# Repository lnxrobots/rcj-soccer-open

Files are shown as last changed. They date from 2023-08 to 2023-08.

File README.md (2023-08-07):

# RoboCup Soccer Open

## Setup

### Install packages and libraries

```
sudo apt install python3-pip git i2c-tools python3-opencv python3-serial python3-websockets
```

```
sudo pip3 install Adafruit-Blinka adafruit-circuitpython-bno055 adafruit-extended-bus adafruit-circuitpython-ssd1306 pillow bluedot
```

### Enable software I2C and second UART, disable builtin Bluetooth

Add following lines to `/boot/config.txt`:

```
# Software i2c - custom
dtoverlay=i2c-gpio,bus=3

# Second and fifth UART - custom
dtoverlay=uart2
dtoverlay=uart5

# Uncomment to disable builtin bluetooth - custom
#dtoverlay=disable-bt
```

### Pairing robots

Pair using [bluedot manual](https://bluedot.readthedocs.io/en/latest/pairpipi.html).

### Camera

Obtain frames using [Picamera2](https://github.com/raspberrypi/picamera2).

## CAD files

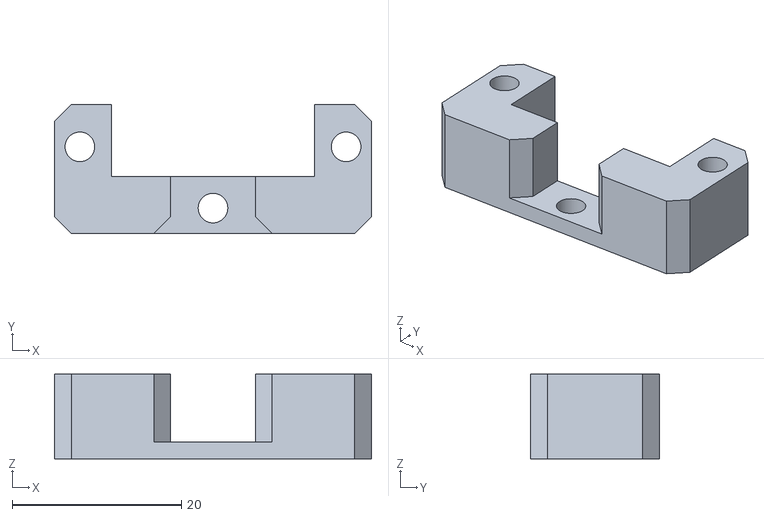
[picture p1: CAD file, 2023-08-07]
Hardware/3D/battery-holders/battery-holder-large-right.stl
37.5 x 15.2 x 10.0

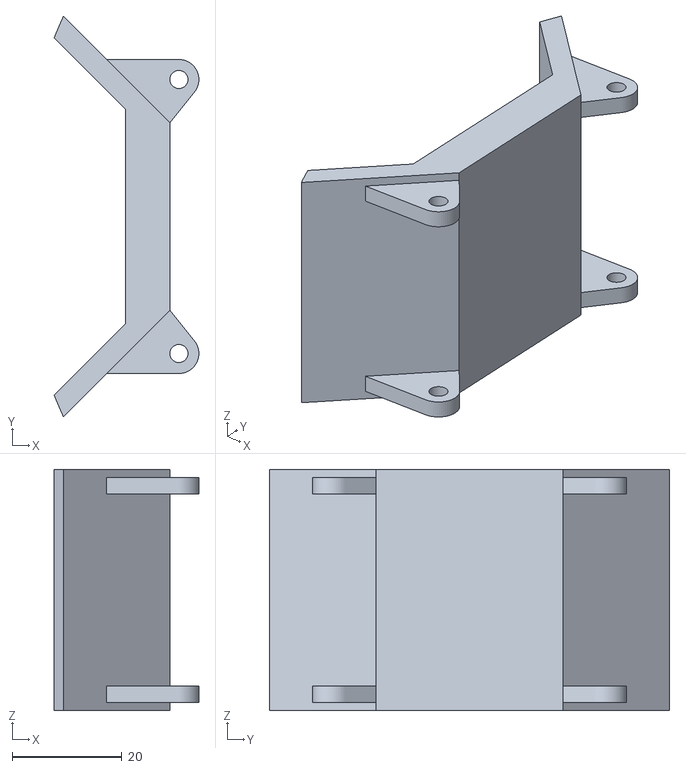
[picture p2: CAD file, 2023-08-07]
Hardware/3D/bumpers-35mm/bumper-front.stl
26.4 x 73.1 x 44.0

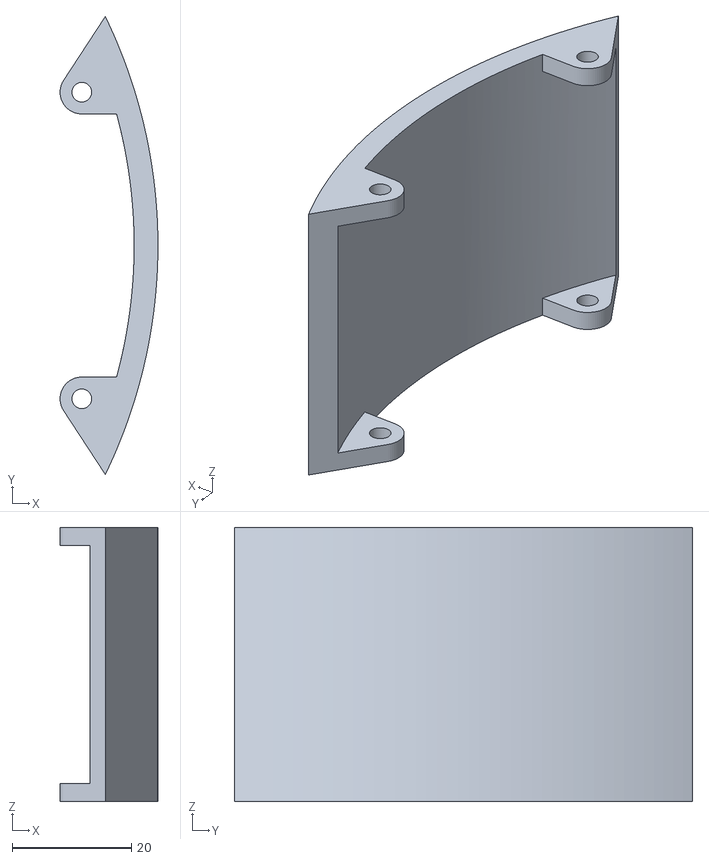
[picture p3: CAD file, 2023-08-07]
Hardware/3D/bumpers-40mm/bumper-40mm-side.stl
16.4 x 76.9 x 46.0

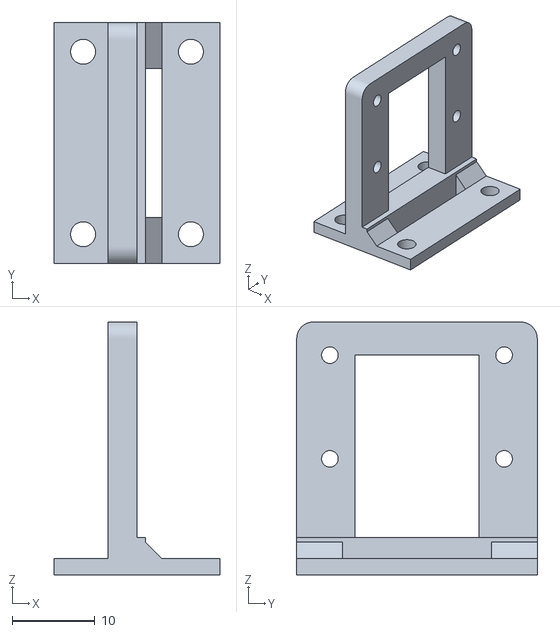
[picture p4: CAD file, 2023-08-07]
Hardware/3D/camera-pcb/camera-mount.stl
20.0 x 29.0 x 30.5

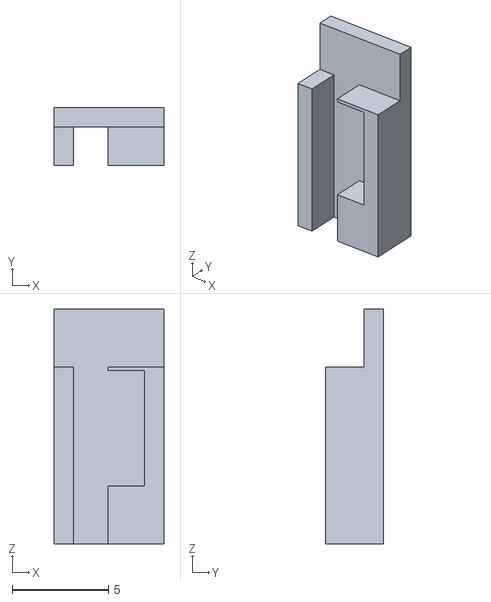
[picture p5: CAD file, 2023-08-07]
Hardware/3D/covers/rpi-led-cover.stl
5.70 x 3.00 x 12.2

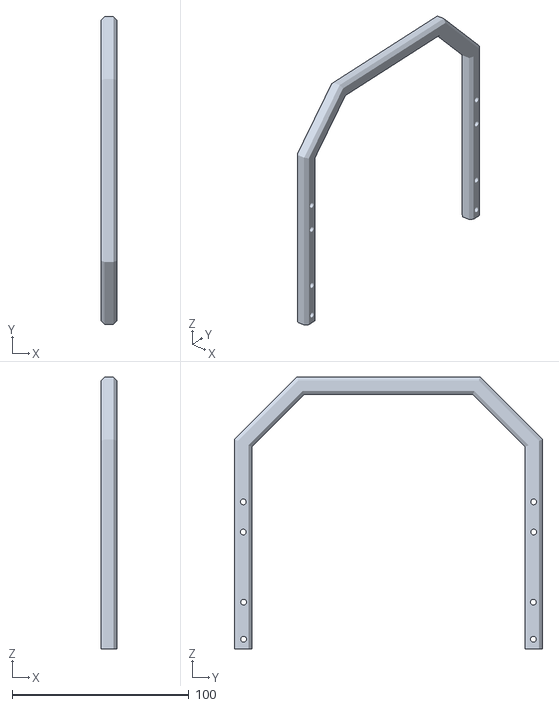
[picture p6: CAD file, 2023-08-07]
Hardware/3D/handle/handle.stl
9.00 x 174.4 x 154.0

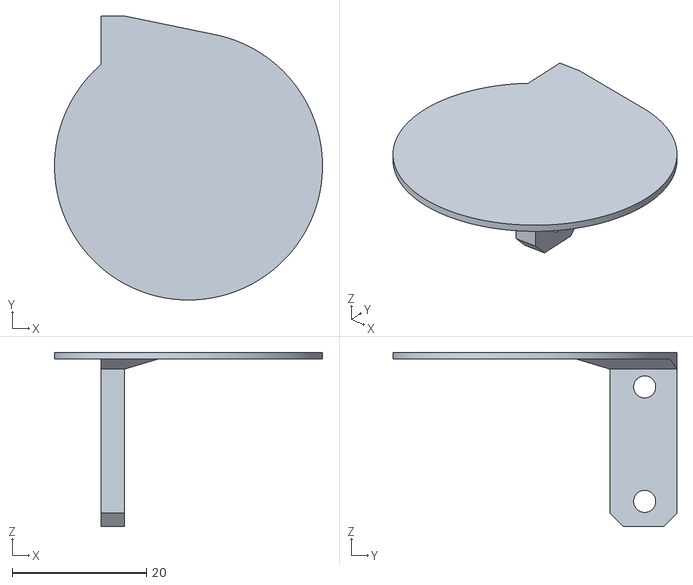
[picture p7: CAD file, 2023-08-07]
Hardware/3D/top-marker.stl
40.0 x 42.4 x 26.0

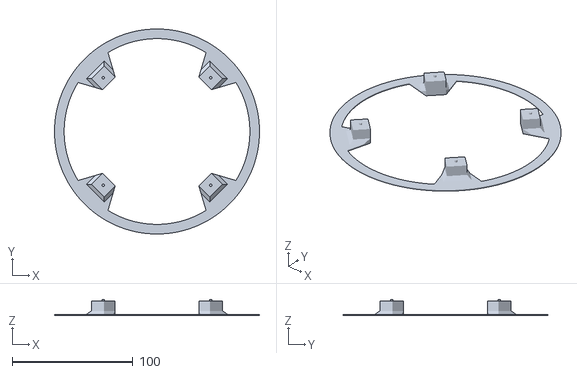
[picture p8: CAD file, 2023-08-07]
Hardware/3D/transport-container-adapter/pad.stl
170.0 x 170.0 x 13.5

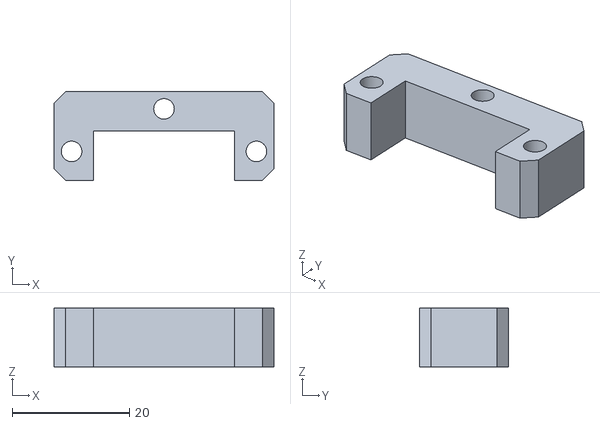
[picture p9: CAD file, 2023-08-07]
Hardware/3D/battery-holders/battery-holder-large-left.stl
37.5 x 15.2 x 10.0

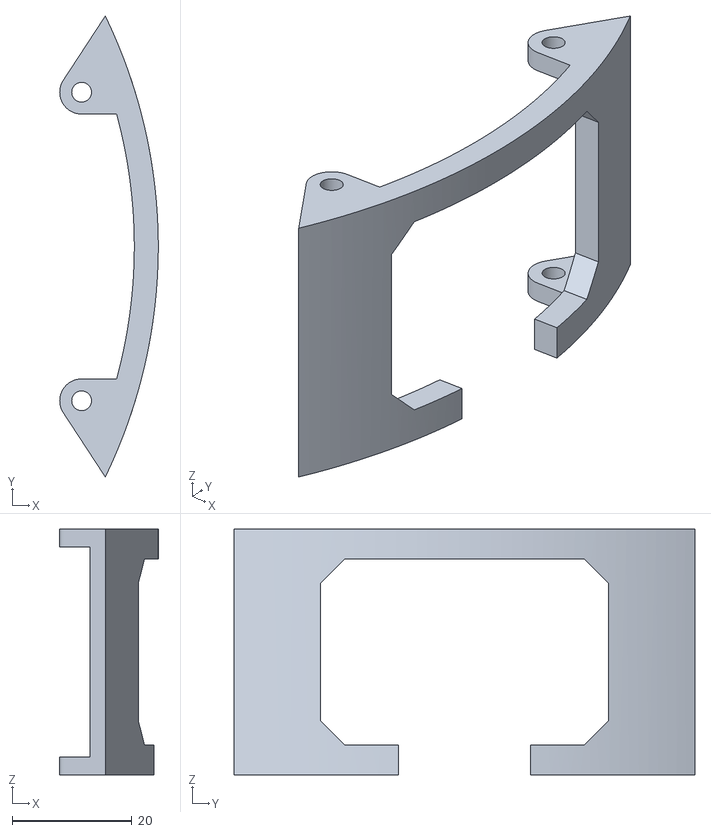
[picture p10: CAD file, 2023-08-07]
Hardware/3D/bumpers-35mm/bumper-rear.stl
16.4 x 76.9 x 41.0

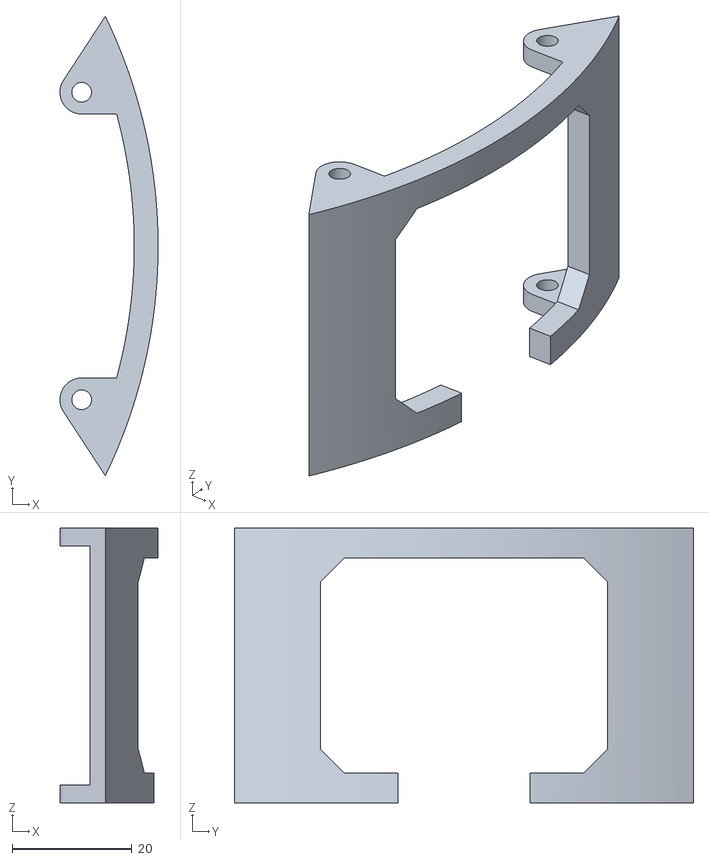
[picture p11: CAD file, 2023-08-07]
Hardware/3D/bumpers-40mm/bumper-40mm-rear.stl
16.4 x 76.9 x 46.0

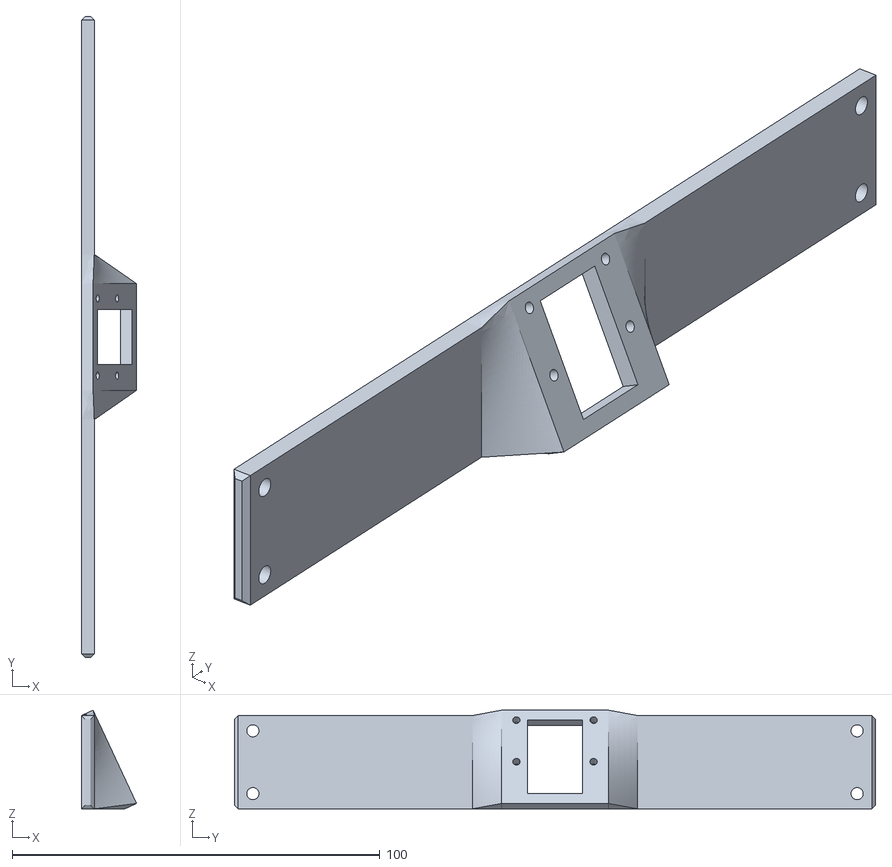
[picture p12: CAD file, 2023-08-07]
Hardware/3D/camera-handle/handle-camera-mount.stl
15.0 x 174.4 x 26.9

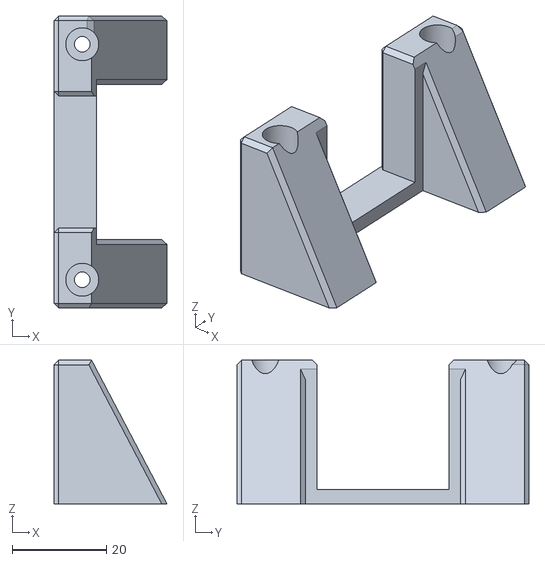
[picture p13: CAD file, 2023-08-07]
Hardware/3D/camera-pcb/camera-protector.stl
24.0 x 62.0 x 30.5

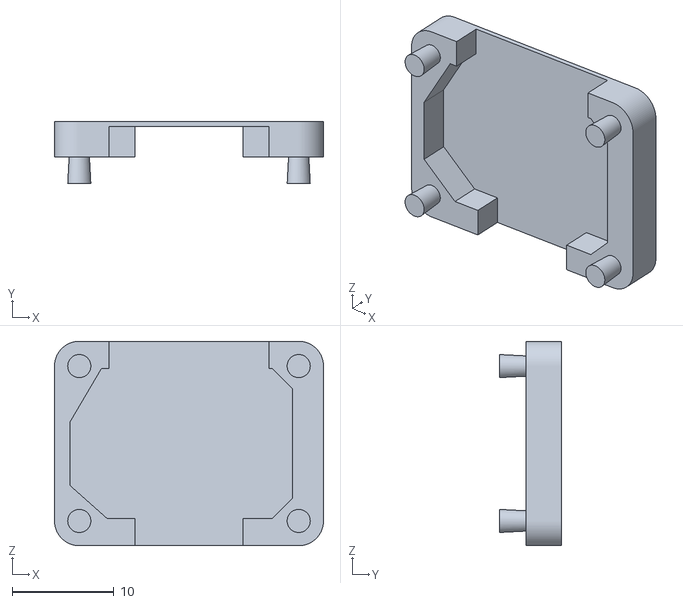
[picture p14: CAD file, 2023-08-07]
Hardware/3D/covers/bno-cover.stl
26.5 x 6.15 x 20.1

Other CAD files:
Hardware/3D/handle/handle-mount.stl
Hardware/3D/rack.stl
Hardware/3D/transport-container-adapter/adapter.stl
Hardware/3D/battery-holders/battery-holder-small-left.stl
Hardware/3D/battery-holders/battery-holder-small-right.stl
Hardware/3D/bumpers-35mm/bumper-side.stl
Hardware/3D/bumpers-40mm/bumper-40mm-front.stl
Hardware/3D/camera-handle/camera-washer.stl
Hardware/3D/motor-screw-washer.stl
Hardware/3D/omniwheel.3mf
Hardware/3D/pcb-shaft.stl
Hardware/3D/rack-only-rpi.stl

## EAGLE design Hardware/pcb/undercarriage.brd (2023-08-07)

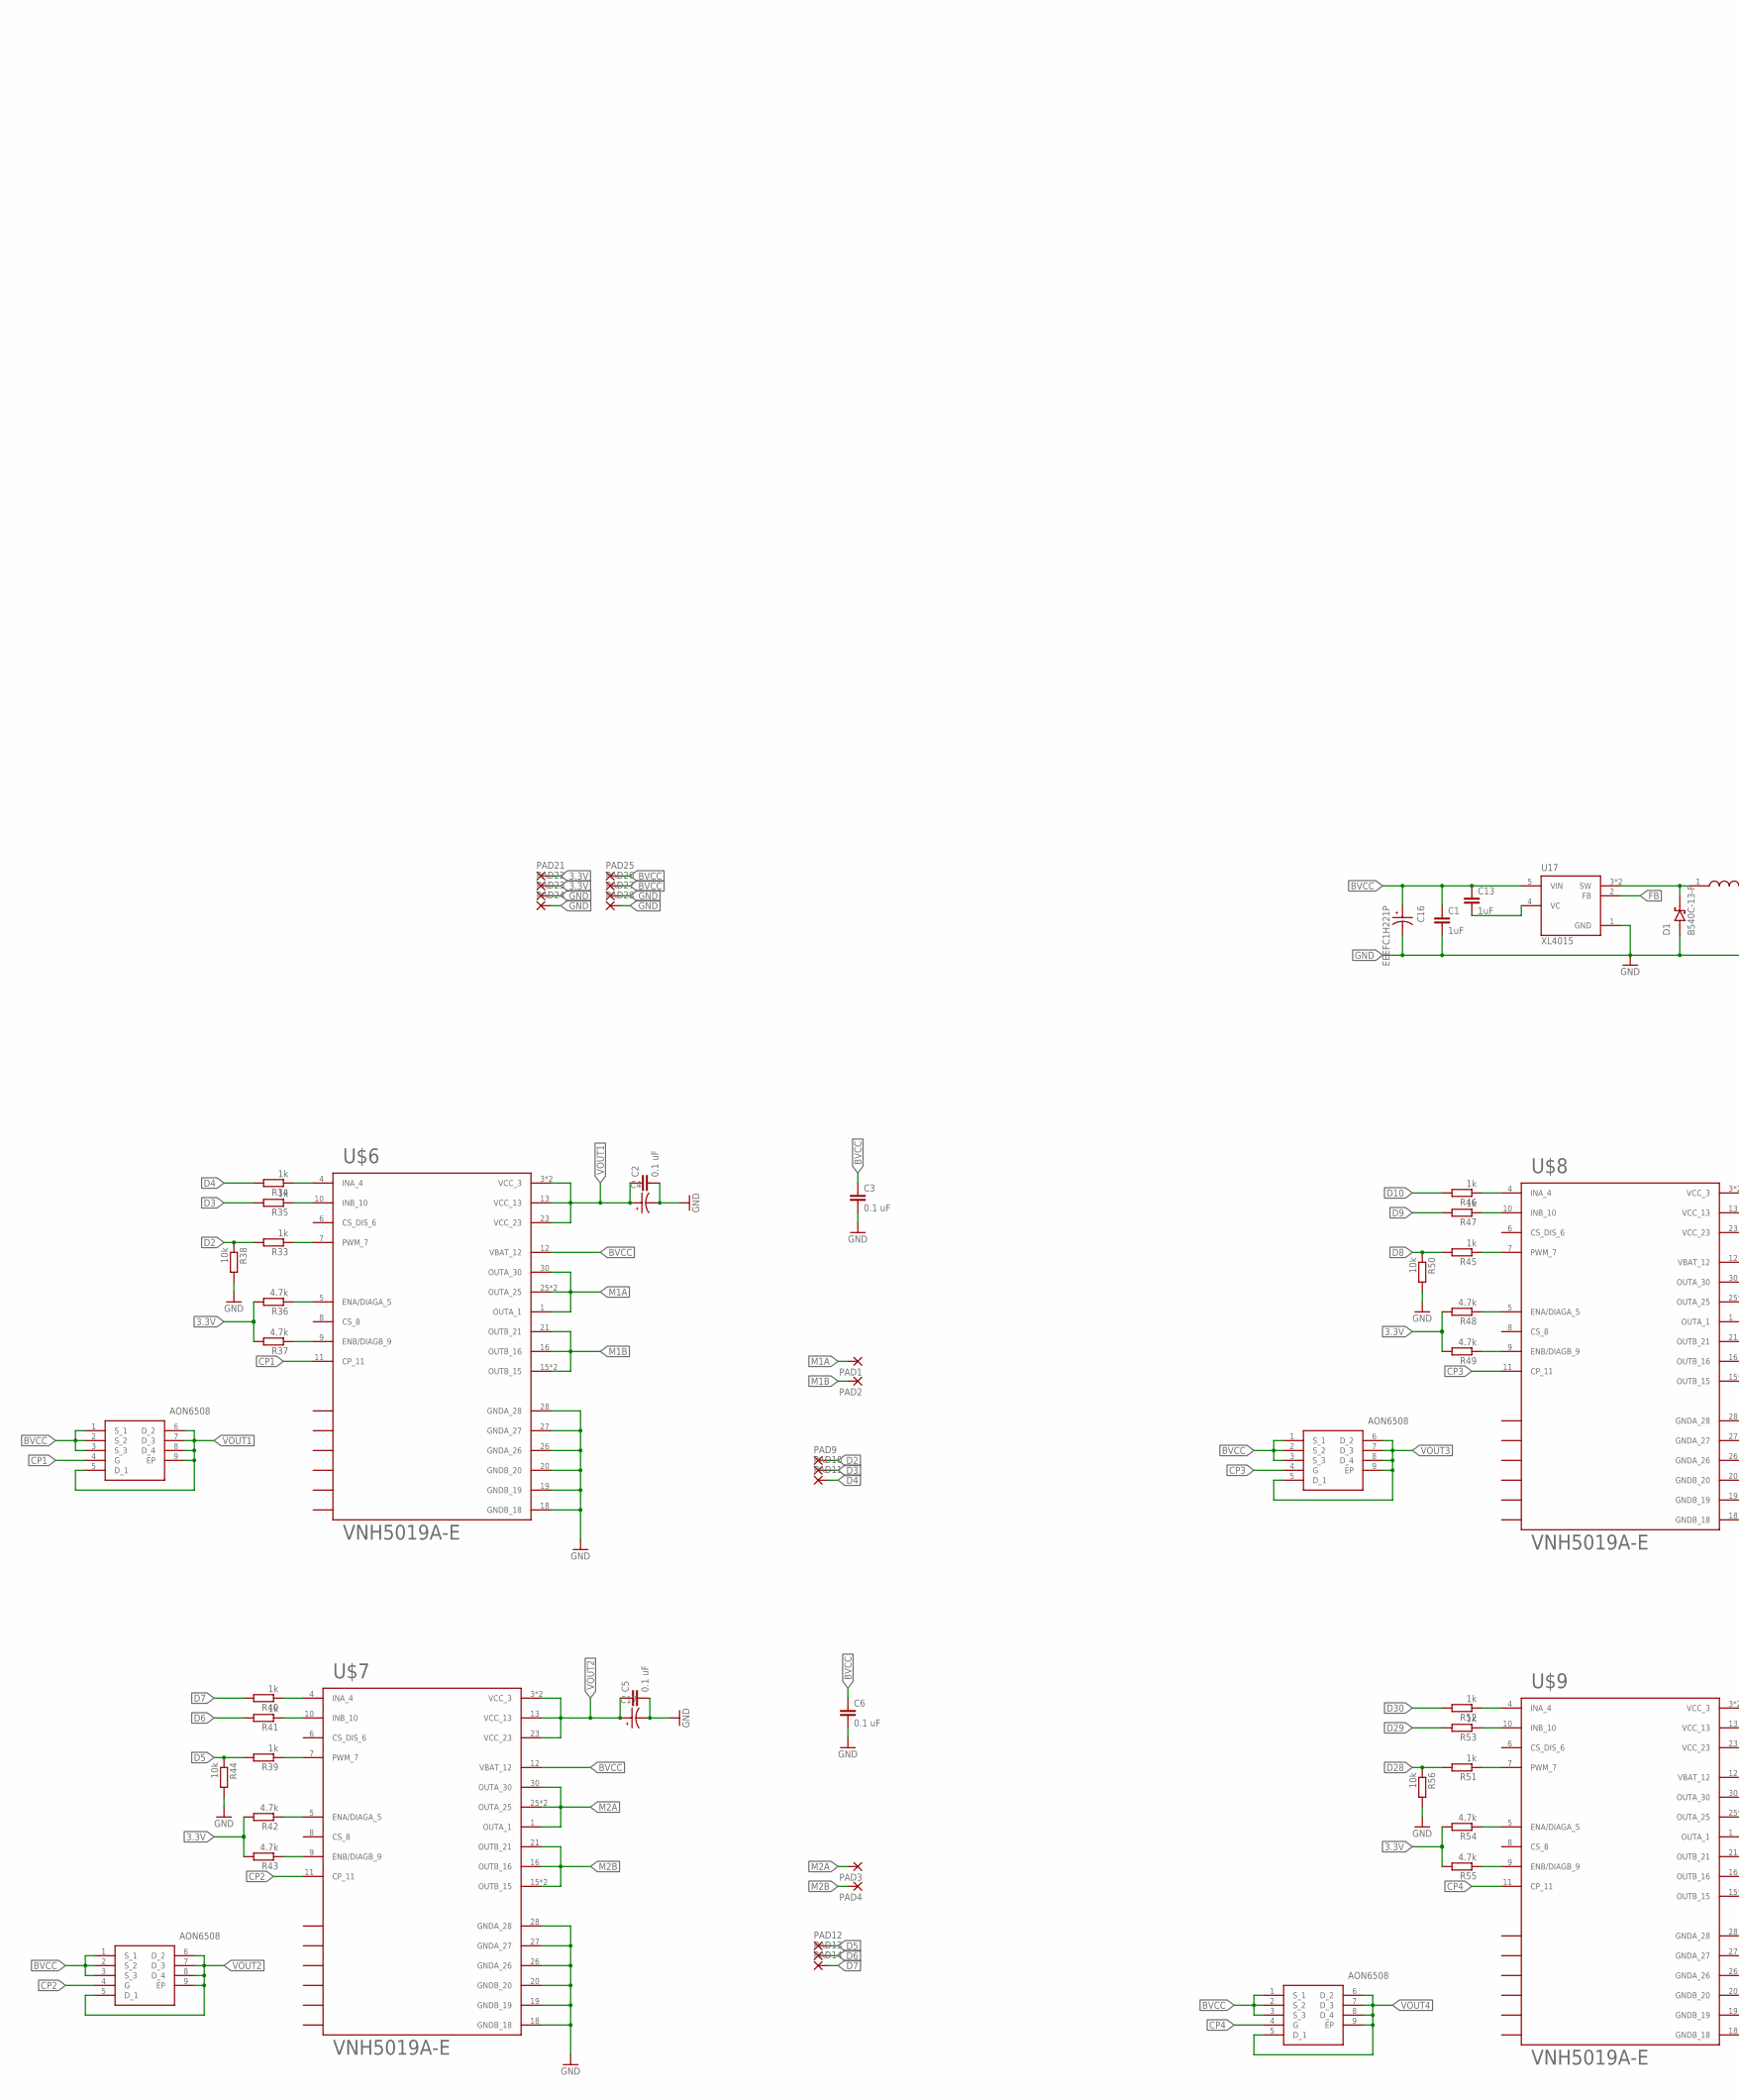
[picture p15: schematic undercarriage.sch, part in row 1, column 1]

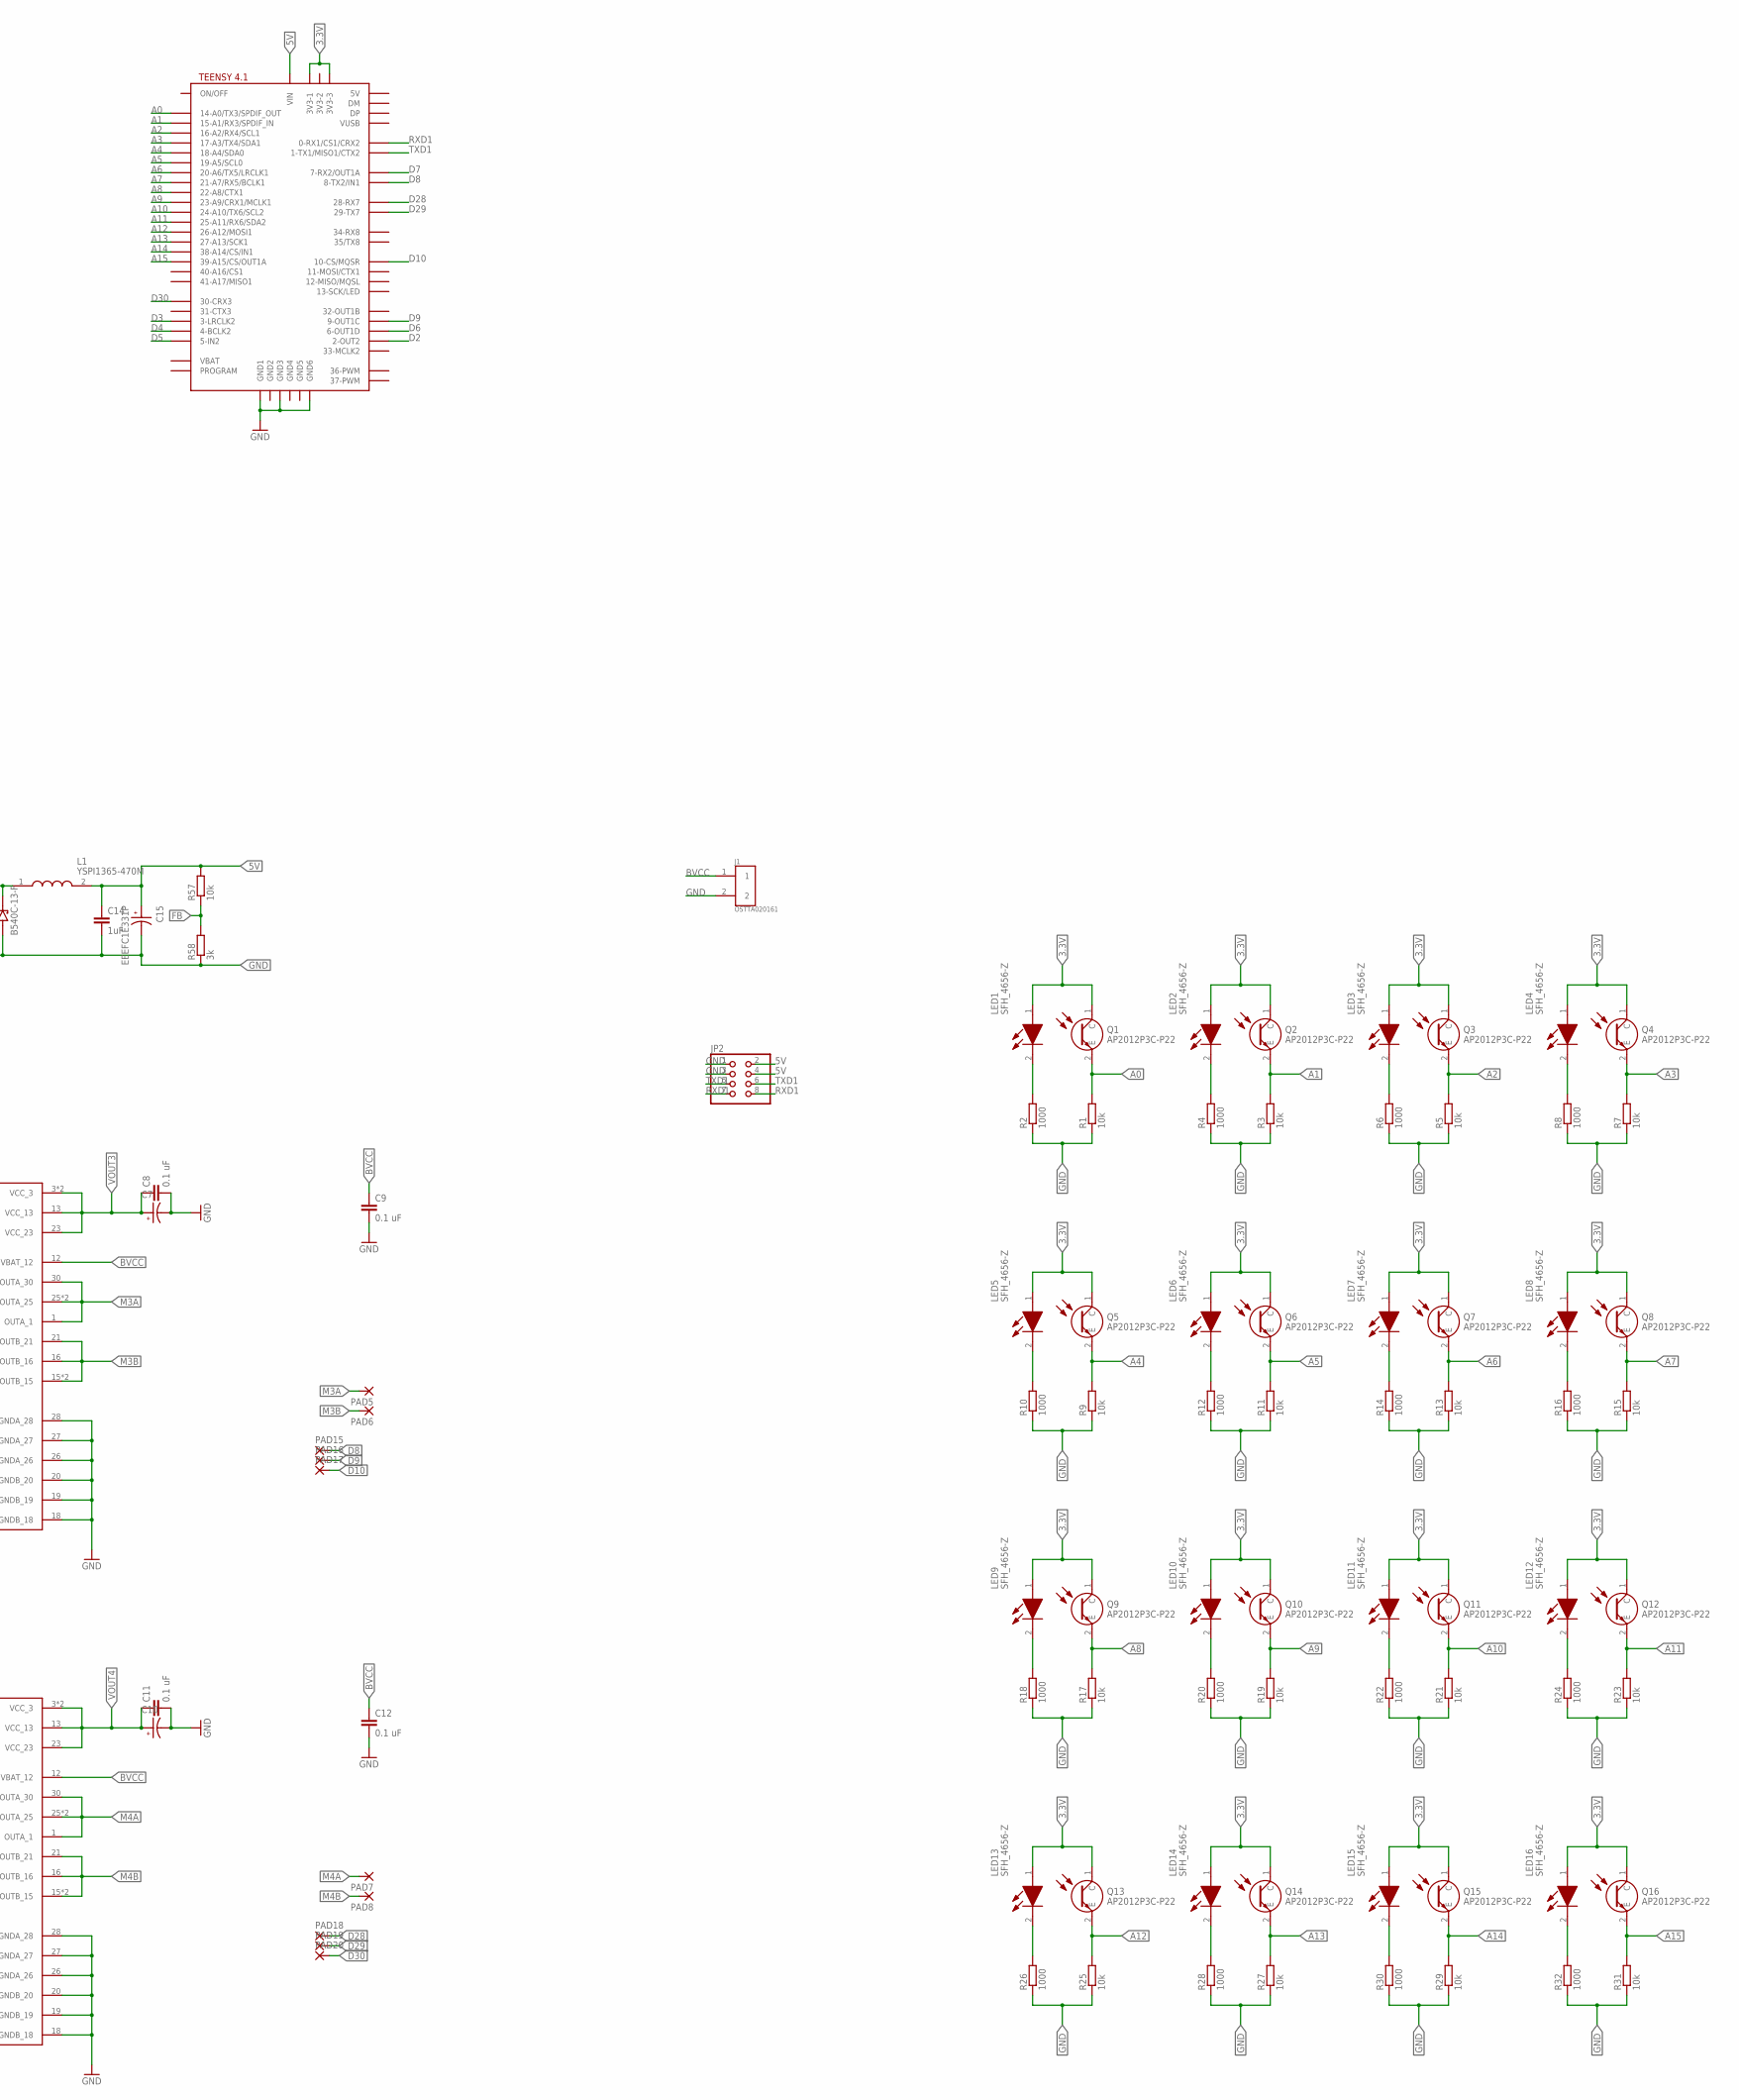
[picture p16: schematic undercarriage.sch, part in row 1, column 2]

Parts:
C1, C13, C14: 1uF; C0603
C2, C3, C5, C6, C8, C9, C11, C12: 0.1 uF; C0603
C4, C7, C10, C17: EEEFT1H470AP; CAP_EEEFT1H470AP
C15: EEEFC1E331P; CAP_EEEFC1E331P
C16: EEEFC1H221P; CAP_EEEFC1H221P
D1: B540C-13-F; DIOM6959X245N
J1: OSTTA020161; OST_OSTTA020161
JP2: PINHD-2X4; 2X04
L1: YSPI1365-470M; INDPM138126X650N
LED1, LED2, LED3, LED4, LED5, LED6, LED7, LED8, LED9, LED10, LED11, LED12, LED13, LED14, LED15, LED16: SFH_4656-Z; SFH4656Z
PAD1, PAD2, PAD3, PAD4, PAD5, PAD6, PAD7, PAD8: 3,81/1,4
PAD9, PAD10, PAD11, PAD12, PAD13, PAD14, PAD15, PAD16, PAD17, PAD18, PAD19, PAD20, PAD21, PAD22, PAD23, PAD24: 1,6/0,9
PAD25, PAD26, PAD27, PAD28: 2,15/1,0
Q1, Q2, Q3, Q4, Q5, Q6, Q7, Q8, Q9, Q10, Q11, Q12, Q13, Q14, Q15, Q16: AP2012P3C-P22; AP2012P3CP22
Q17, Q18, Q19, Q20: AON6508
R1, R3, R5, R7, R9, R11, R13, R15, R17, R19, R21, R23, R25, R27, R29, R31, R38, R44, R50, R56, R57: 10k; R0603
R2, R4, R6, R8, R10, R12, R14, R16, R18, R20, R22, R24, R26, R28, R30, R32: 1000; R0603
R33, R34, R35, R39, R40, R41, R45, R46, R47, R51, R52, R53: 1k; R0603
R36, R37, R42, R43, R48, R49, R54, R55: 4.7k; R0603
R58: 3k; R0603
U17: XL4015; CONV_XL4015
U$5: TEENSY41-E; TENNSY41-E
U$6, U$7, U$8, U$9: VNH5019A-E; IC_MULTIPOWERSO-30TR

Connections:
3.3V: LED1.1 (A), LED2.1 (A), LED3.1 (A), LED4.1 (A), LED5.1 (A), LED6.1 (A), LED7.1 (A), LED8.1 (A), LED9.1 (A), LED10.1 (A), LED11.1 (A), LED12.1 (A), LED13.1 (A), LED14.1 (A), LED15.1 (A), LED16.1 (A), PAD21.1, PAD22.1, Q1.1 (C), Q2.1 (C), Q3.1 (C), Q4.1 (C), Q5.1 (C), Q6.1 (C), Q7.1 (C), Q8.1 (C), Q9.1 (C), Q10.1 (C), Q11.1 (C), Q12.1 (C), Q13.1 (C), Q14.1 (C), Q15.1 (C), Q16.1 (C), R36.2, R37.2, R42.2, R43.2, R48.2, R49.2, R54.2, R55.2, U$5.3V3-1, U$5.3V3-3
5V: C14.1, C15.1, JP2.2, JP2.4, L1.2, R57.2, U$5.VIN
A0: Q1.2 (E), R1.2, U$5.14-A0/TX3/SPDIF_OUT
A1: Q2.2 (E), R3.2, U$5.15-A1/RX3/SPDIF_IN
A2: Q3.2 (E), R5.2, U$5.16-A2/RX4/SCL1
A3: Q4.2 (E), R7.2, U$5.17-A3/TX4/SDA1
A4: Q5.2 (E), R9.2, U$5.18-A4/SDA0
A5: Q6.2 (E), R11.2, U$5.19-A5/SCL0
A6: Q7.2 (E), R13.2, U$5.20-A6/TX5/LRCLK1
A7: Q8.2 (E), R15.2, U$5.21-A7/RX5/BCLK1
A8: Q9.2 (E), R17.2, U$5.22-A8/CTX1
A9: Q10.2 (E), R19.2, U$5.23-A9/CRX1/MCLK1
A10: Q11.2 (E), R21.2, U$5.24-A10/TX6/SCL2
A11: Q12.2 (E), R23.2, U$5.25-A11/RX6/SDA2
A12: Q13.2 (E), R25.2, U$5.26-A12/MOSI1
A13: Q14.2 (E), R27.2, U$5.27-A13/SCK1
A14: Q15.2 (E), R29.2, U$5.38-A14/CS/IN1
A15: Q16.2 (E), R31.2, U$5.39-A15/CS/OUT1A
BVCC: C1.1, C3.1, C6.1, C9.1, C12.1, C13.1, C16.1, J1.1, PAD25.1, PAD26.1, Q17.1 (S_1), Q17.2 (S_2), Q17.3 (S_3), Q18.1 (S_1), Q18.2 (S_2), Q18.3 (S_3), Q19.1 (S_1), Q19.2 (S_2), Q19.3 (S_3), Q20.1 (S_1), Q20.2 (S_2), Q20.3 (S_3), U17.5 (VIN), U$6.12 (VBAT_12), U$7.12 (VBAT_12), U$8.12 (VBAT_12), U$9.12 (VBAT_12)
CP1: Q17.4 (G), U$6.11 (CP_11)
CP2: Q18.4 (G), U$7.11 (CP_11)
CP3: Q20.4 (G), U$8.11 (CP_11)
CP4: Q19.4 (G), U$9.11 (CP_11)
D2: PAD9.1, R33.2, R38.1, U$5.2-OUT2
D3: PAD10.1, R35.2, U$5.3-LRCLK2
D4: PAD11.1, R34.2, U$5.4-BCLK2
D5: PAD12.1, R39.2, R44.1, U$5.5-IN2
D6: PAD13.1, R41.2, U$5.6-OUT1D
D7: PAD14.1, R40.2, U$5.7-RX2/OUT1A
D8: PAD15.1, R45.2, R50.1, U$5.8-TX2/IN1
D9: PAD16.1, R47.2, U$5.9-OUT1C
D10: PAD17.1, R46.2, U$5.10-CS\MQSR (10-CS/MQSR)
D28: PAD18.1, R51.2, R56.1, U$5.28-RX7
D29: PAD19.1, R53.2, U$5.29-TX7
D30: PAD20.1, R52.2, U$5.30-CRX3
FB: R57.1, R58.2, U17.2 (FB)
GND: C1.2, C2.2, C3.2, C4.2, C5.2, C6.2, C7.2, C8.2, C9.2, C10.2, C11.2, C12.2, C14.2, C15.2, C16.2, C17.2, D1.A, J1.2, JP2.1, JP2.3, PAD23.1, PAD24.1, PAD27.1, PAD28.1, R1.1, R2.1, R3.1, R4.1, R5.1, R6.1, R7.1, R8.1, R9.1, R10.1, R11.1, R12.1, R13.1, R14.1, R15.1, R16.1, R17.1, R18.1, R19.1, R20.1, R21.1, R22.1, R23.1, R24.1, R25.1, R26.1, R27.1, R28.1, R29.1, R30.1, R31.1, R32.1, R38.2, R44.2, R50.2, R56.2, R58.1, U17.1 (GND), U$5.GND1, U$5.GND3, U$5.GND6, U$6.18 (GNDB_18), U$6.19 (GNDB_19), U$6.20 (GNDB_20), U$6.26 (GNDA_26), U$6.27 (GNDA_27), U$6.28 (GNDA_28), U$7.18 (GNDB_18), U$7.19 (GNDB_19), U$7.20 (GNDB_20), U$7.26 (GNDA_26), U$7.27 (GNDA_27), U$7.28 (GNDA_28), U$8.18 (GNDB_18), U$8.19 (GNDB_19), U$8.20 (GNDB_20), U$8.26 (GNDA_26), U$8.27 (GNDA_27), U$8.28 (GNDA_28), U$9.18 (GNDB_18), U$9.19 (GNDB_19), U$9.20 (GNDB_20), U$9.26 (GNDA_26), U$9.27 (GNDA_27), U$9.28 (GNDA_28)
M1A: PAD1.1, U$6.1 (OUTA_1), U$6.25 (OUTA_25), U$6.30 (OUTA_30), U$6.HS2 (OUTA_25)
M1B: PAD2.1, U$6.15 (OUTB_15), U$6.16 (OUTB_16), U$6.21 (OUTB_21), U$6.HS3 (OUTB_15)
M2A: PAD3.1, U$7.1 (OUTA_1), U$7.25 (OUTA_25), U$7.30 (OUTA_30), U$7.HS2 (OUTA_25)
M2B: PAD4.1, U$7.15 (OUTB_15), U$7.16 (OUTB_16), U$7.21 (OUTB_21), U$7.HS3 (OUTB_15)
M3A: PAD5.1, U$8.1 (OUTA_1), U$8.25 (OUTA_25), U$8.30 (OUTA_30), U$8.HS2 (OUTA_25)
M3B: PAD6.1, U$8.15 (OUTB_15), U$8.16 (OUTB_16), U$8.21 (OUTB_21), U$8.HS3 (OUTB_15)
M4A: PAD7.1, U$9.1 (OUTA_1), U$9.25 (OUTA_25), U$9.30 (OUTA_30), U$9.HS2 (OUTA_25)
M4B: PAD8.1, U$9.15 (OUTB_15), U$9.16 (OUTB_16), U$9.21 (OUTB_21), U$9.HS3 (OUTB_15)
unnamed: LED2.2 (K), R4.2
unnamed: LED3.2 (K), R6.2
unnamed: LED1.2 (K), R2.2
unnamed: LED4.2 (K), R8.2
unnamed: R33.1, U$6.7 (PWM_7)
unnamed: R34.1, U$6.4 (INA_4)
unnamed: C13.2, U17.4 (VC)
unnamed: R35.1, U$6.10 (INB_10)
unnamed: LED5.2 (K), R10.2
unnamed: LED6.2 (K), R12.2
unnamed: R37.1, U$6.9 (ENB/DIAGB_9)
unnamed: R36.1, U$6.5 (ENA/DIAGA_5)
unnamed: R39.1, U$7.7 (PWM_7)
unnamed: R40.1, U$7.4 (INA_4)
unnamed: R41.1, U$7.10 (INB_10)
unnamed: R43.1, U$7.9 (ENB/DIAGB_9)
unnamed: LED7.2 (K), R14.2
unnamed: LED8.2 (K), R16.2
unnamed: LED9.2 (K), R18.2
unnamed: LED10.2 (K), R20.2
unnamed: LED11.2 (K), R22.2
unnamed: LED12.2 (K), R24.2
unnamed: LED13.2 (K), R26.2
unnamed: LED14.2 (K), R28.2
unnamed: LED15.2 (K), R30.2
unnamed: LED16.2 (K), R32.2
unnamed: R42.1, U$7.5 (ENA/DIAGA_5)
unnamed: R45.1, U$8.7 (PWM_7)
unnamed: R46.1, U$8.4 (INA_4)
unnamed: R47.1, U$8.10 (INB_10)
unnamed: R49.1, U$8.9 (ENB/DIAGB_9)
unnamed: R48.1, U$8.5 (ENA/DIAGA_5)
unnamed: R51.1, U$9.7 (PWM_7)
unnamed: R52.1, U$9.4 (INA_4)
unnamed: R53.1, U$9.10 (INB_10)
unnamed: R55.1, U$9.9 (ENB/DIAGB_9)
unnamed: R54.1, U$9.5 (ENA/DIAGA_5)
unnamed: D1.C (K), L1.1, U17.3 (SW), U17.3.1 (SW)
RXD1: JP2.7, JP2.8, U$5.0-RX1/CS1/CRX2
TXD1: JP2.5, JP2.6, U$5.1-TX1/MISO1/CTX2
VOUT1: C2.1, C4.1, Q17.5 (D_1), Q17.6 (D_2), Q17.7 (D_3), Q17.8 (D_4), Q17.9 (EP), U$6.3 (VCC_3), U$6.13 (VCC_13), U$6.23 (VCC_23), U$6.HS1 (VCC_3)
VOUT2: C5.1, C17.1, Q18.5 (D_1), Q18.6 (D_2), Q18.7 (D_3), Q18.8 (D_4), Q18.9 (EP), U$7.3 (VCC_3), U$7.13 (VCC_13), U$7.23 (VCC_23), U$7.HS1 (VCC_3)
VOUT3: C7.1, C8.1, Q20.5 (D_1), Q20.6 (D_2), Q20.7 (D_3), Q20.8 (D_4), Q20.9 (EP), U$8.3 (VCC_3), U$8.13 (VCC_13), U$8.23 (VCC_23), U$8.HS1 (VCC_3)
VOUT4: C10.1, C11.1, Q19.5 (D_1), Q19.6 (D_2), Q19.7 (D_3), Q19.8 (D_4), Q19.9 (EP), U$9.3 (VCC_3), U$9.13 (VCC_13), U$9.23 (VCC_23), U$9.HS1 (VCC_3)

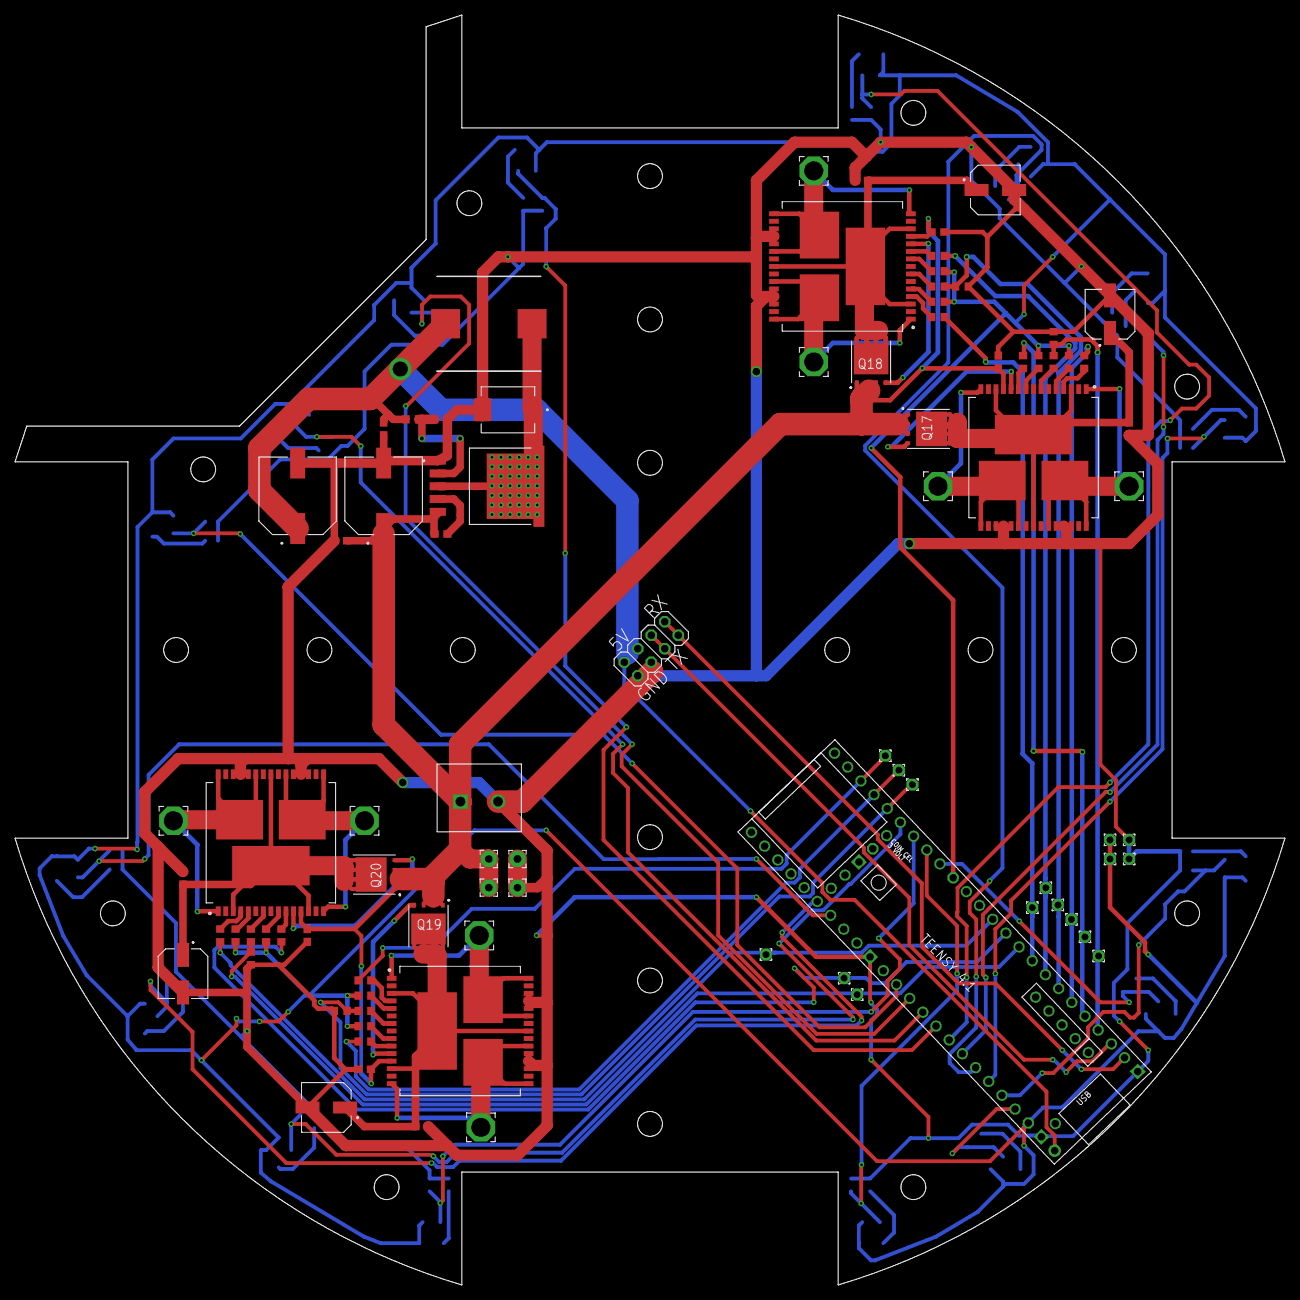
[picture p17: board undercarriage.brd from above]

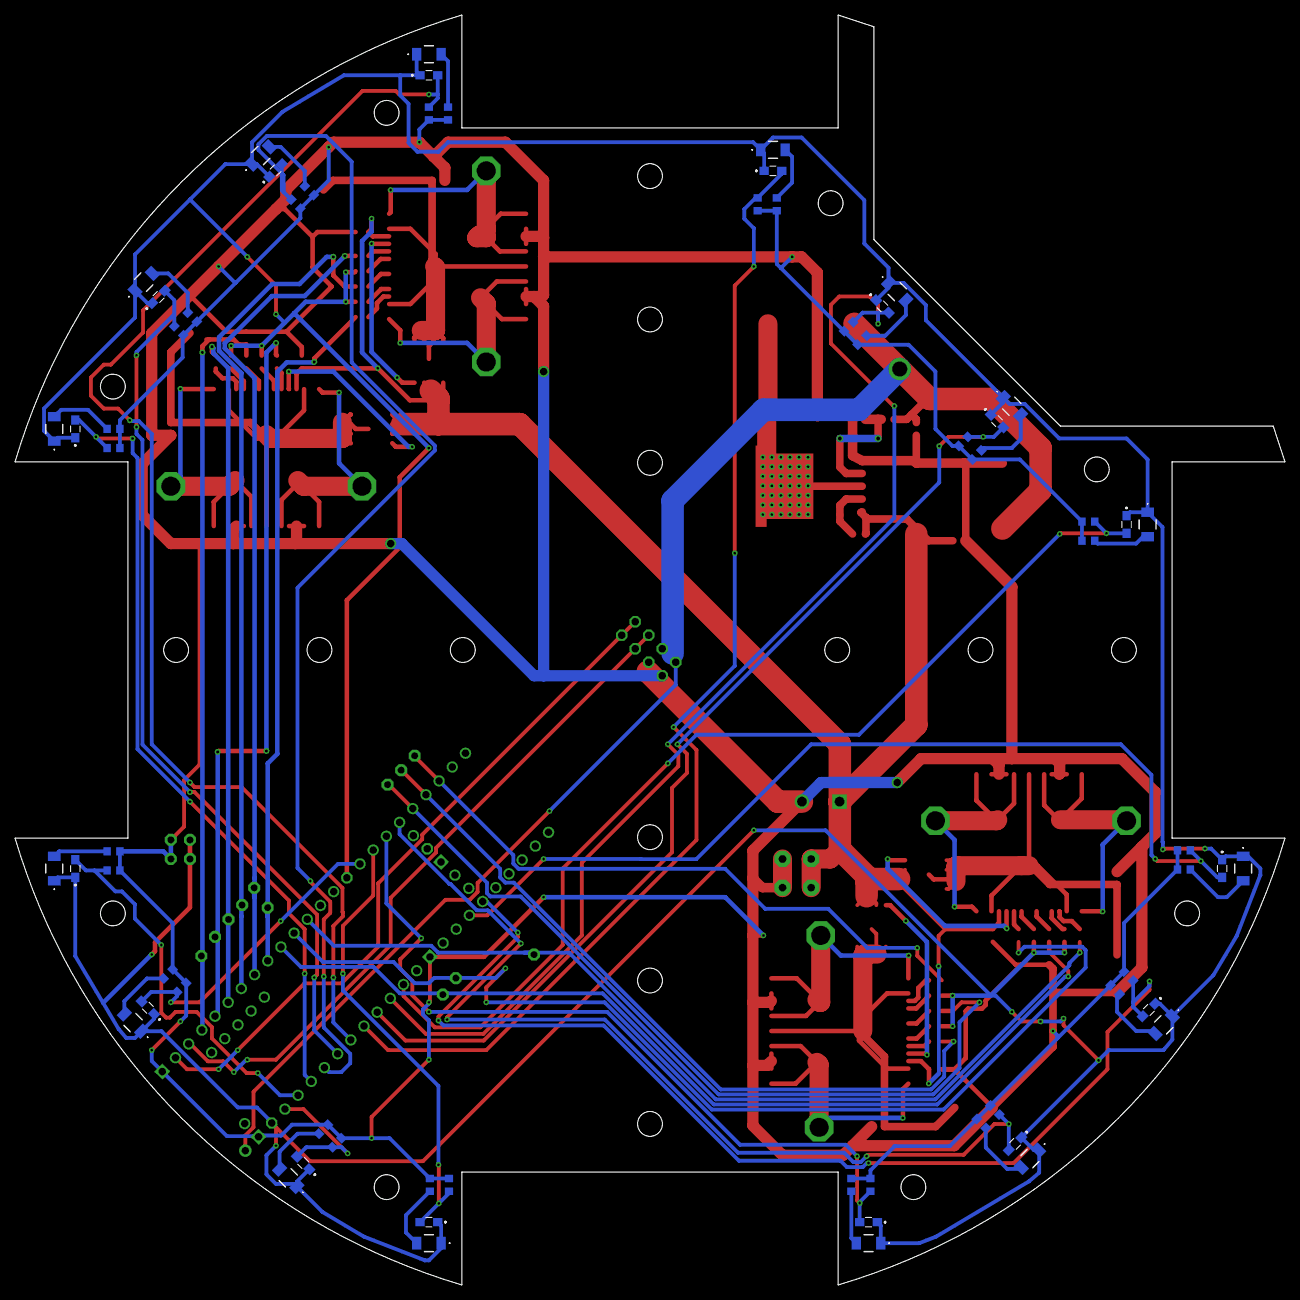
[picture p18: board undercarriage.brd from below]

Board: 2 copper layers, 168.7 x 168.7 mm, 149 parts (64 on the bottom side), 89 nets.

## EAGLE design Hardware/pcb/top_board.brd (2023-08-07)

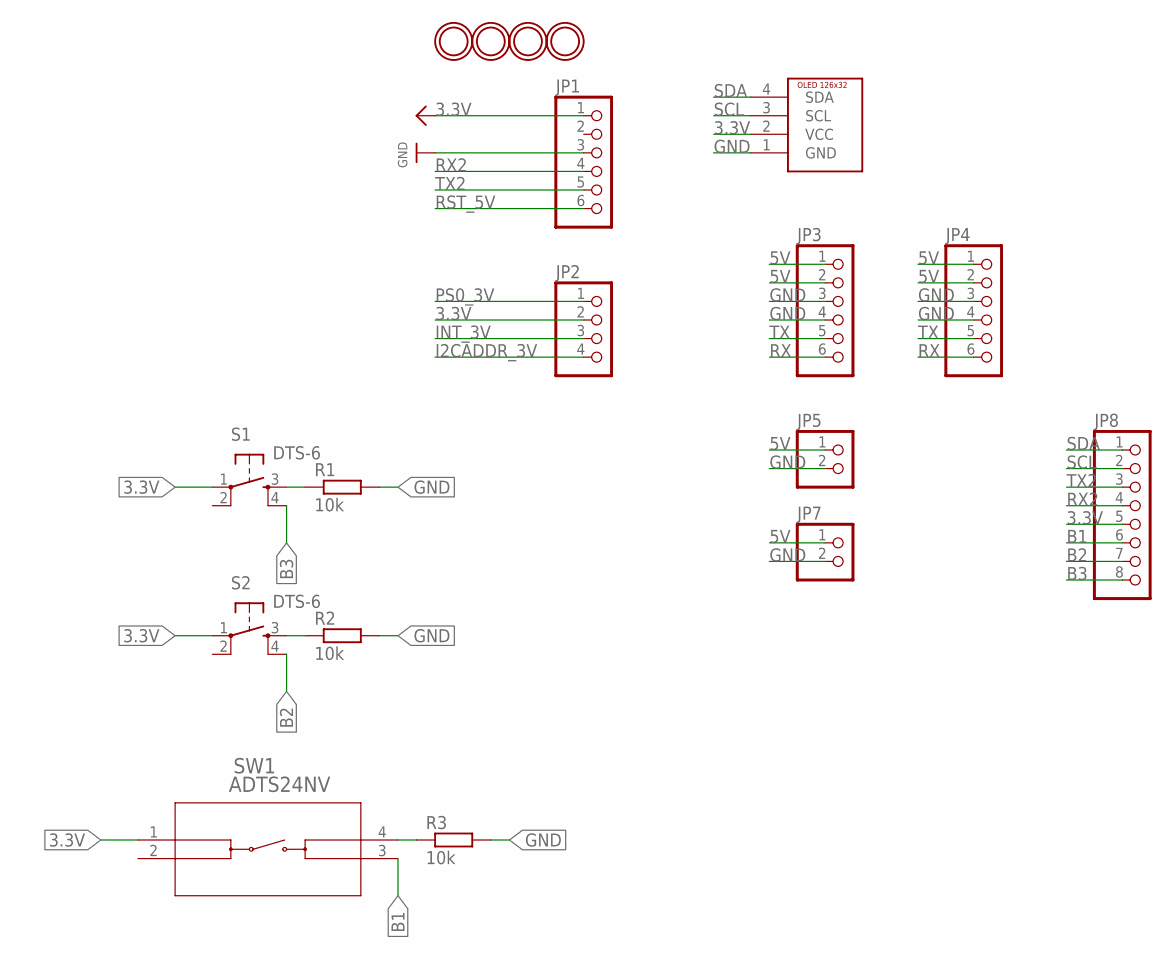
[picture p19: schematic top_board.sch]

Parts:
JP1: HEADER-1X676MIL; 1X06_ROUND_76
JP2: HEADER-1X476MIL; 1X04_ROUND_76
JP3, JP4: PINHD-1X6; 1X06
JP5, JP7: PINHD-1X2; 1X02
JP8: PINHD-1X8; 1X08
R1, R2, R3: 10k; R0603
S1, S2: DTS-6
SW1: ADTS24NV; ADTS24*V_APM
U$1: OLED126X32THROUGH_HOLE; OLED128X64
U$29, U$30, U$31, U$32: MOUNTINGHOLE2.5_THICK; MOUNTINGHOLE_2.5_PLATED_THICK

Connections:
3.3V: JP1.1, JP2.2, JP8.5, S1.1, S2.1, SW1.1, U$1.2 (VCC)
5V: JP3.1, JP3.2, JP4.1, JP4.2, JP5.1, JP7.1
B1: JP8.6, SW1.3
B2: JP8.7, S2.4
B3: JP8.8, S1.4
GND: JP1.3, JP3.3, JP3.4, JP4.3, JP4.4, JP5.2, JP7.2, R1.2, R2.2, R3.2, U$1.1 (GND)
I2CADDR_3V: JP2.4
INT_3V: JP2.3
unnamed: R1.1, S1.3
unnamed: R2.1, S2.3
unnamed: R3.1, SW1.4
PS0_3V: JP2.1
RST_5V: JP1.6
RX: JP3.6, JP4.6
RX2: JP1.4, JP8.4
SCL: JP8.2, U$1.3 (SCL)
SDA: JP8.1, U$1.4 (SDA)
TX: JP3.5, JP4.5
TX2: JP1.5, JP8.3

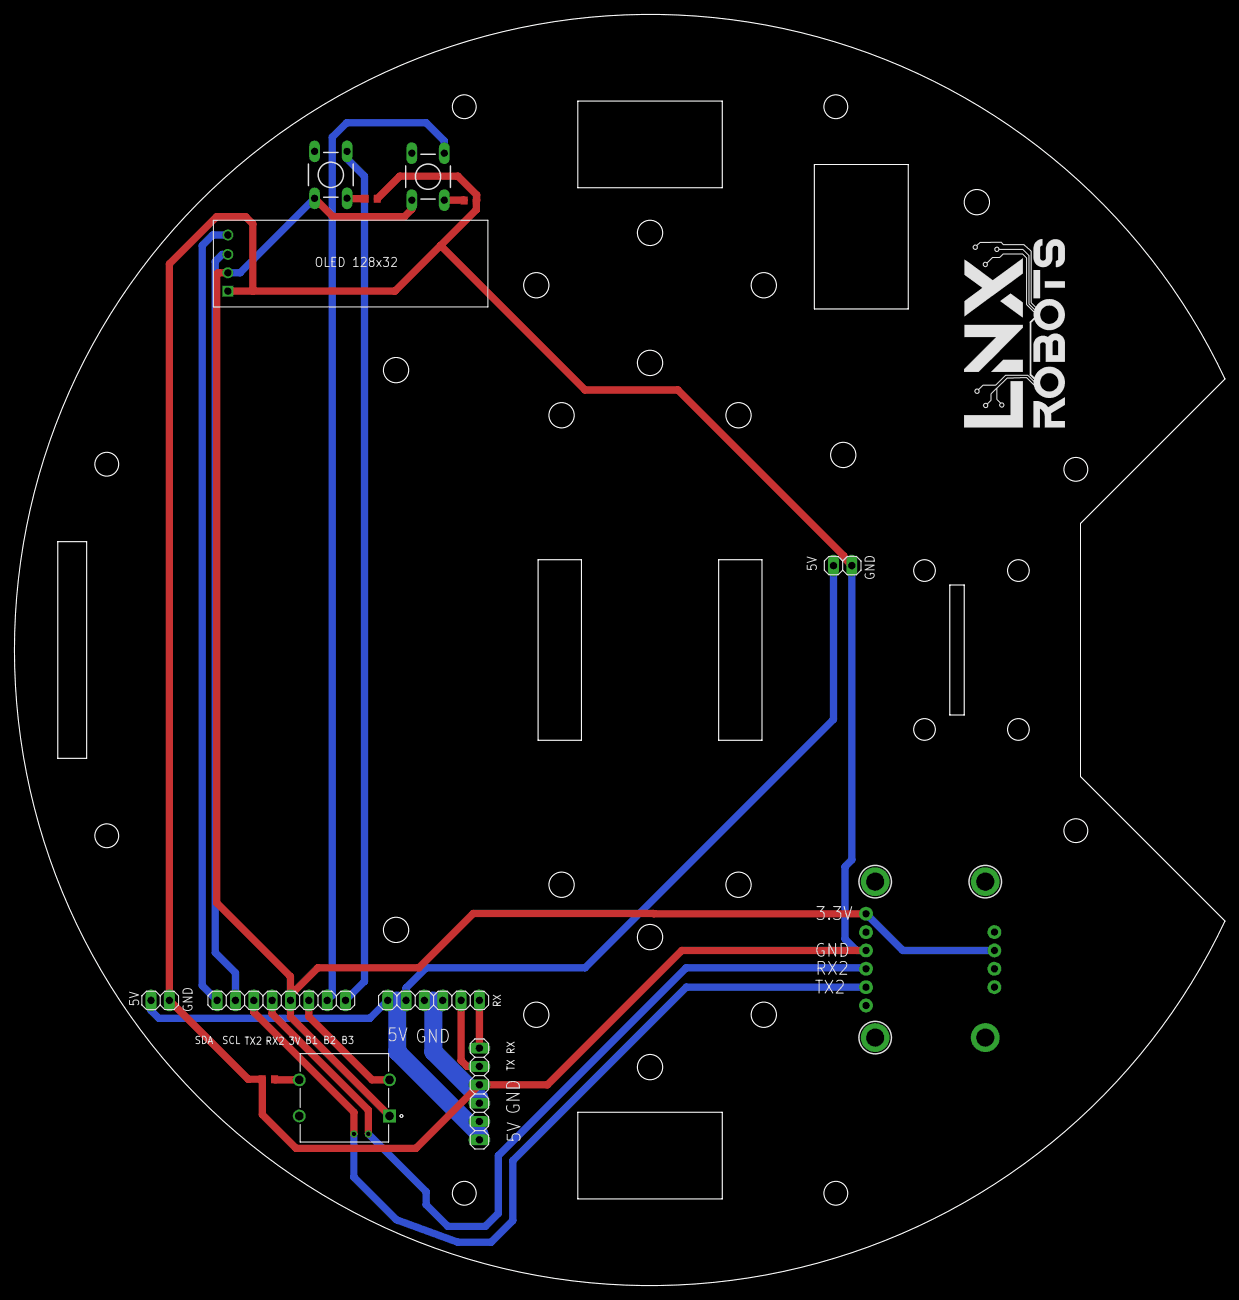
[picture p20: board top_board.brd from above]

Board: 2 copper layers, 167.6 x 176.0 mm, 18 parts (1 on the bottom side), 15 nets.

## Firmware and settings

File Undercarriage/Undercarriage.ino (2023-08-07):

#include <ArduinoJson.h>

#define SENSOR_COUNT 16
#define MOTOR_COUNT 4

const unsigned int sensorPins[SENSOR_COUNT] = {
  A1,  A3,  A4,  A6,
  A5,  A7,  A8,  A10,
  A9,  A11, A12, A13,
  A14, A15, A0,  A2,
};

const unsigned int motorPins[MOTOR_COUNT][3] = {
  {5, 6, 7},
  {2, 3, 4},
  {28, 29, 30},
  {8, 9, 10},
};

const int builtinLedPin = LED_BUILTIN;
bool builtinLedStatus = false;

bool isConnected = false;

const unsigned int connectionTimeout = 1000;
const unsigned int sensorMessageInterval = 8;

unsigned long lastTime = 0;
unsigned long lastMessageTime = 0;
unsigned long lastSensorsMessage = 0;

unsigned long communicationLogTimeStart = 0;
unsigned long communicationLogTime = -1; 
const int LOG_COMM = 1;

const int DEBUG_SERIAL_WRITE = 0;

int motorMessageCount = 0;
int sensorMessageCount = 0;

int motorConf = 0;

int motorValues[4];
int colorSensorValues[SENSOR_COUNT] = {
  0, 0, 0, 0,
  0, 0, 0, 0,
  0, 0, 0, 0,
  0, 0, 0, 0,
};

enum MessageType
{
  NONE = -1,
  INIT, DISCONNECT, ERROR, MOTORS, SENSORS,
  SENSOR_STAT_RESET_RQ, SENSOR_STAT_RESET_RS, SENSOR_STAT_READ_RQ, SENSOR_STAT_READ_RS,
  SENSOR_LOG_READ_RQ, SENSOR_LOG_READ_RS 
};

String CreateErrorJson(const String& errorMessage)
{
  StaticJsonDocument<1024> outMessage;

  outMessage["type"] = MessageType::ERROR;
  outMessage["message"] = errorMessage;

  String outString = "";

  serializeJson(outMessage, outString);

  return outString;
}

void SetMotor(int m, int v)
{
  bool polarity = v >= 0;
  analogWrite(motorPins[m][0], abs(v));
  digitalWrite(motorPins[m][1], !polarity);
  digitalWrite(motorPins[m][2], polarity);
}

void SetMotors(int v1, int v2, int v3, int v4)
{
  if (motorConf == 2){
    SetMotor(1, -v1);
    SetMotor(2, -v2);
    SetMotor(3, -v3);
    SetMotor(0, -v4);  
  } else {
    SetMotor(0, v1);
    SetMotor(1, v2);
    SetMotor(2, v3);
    SetMotor(3, v4);
  }
}

String readSerialData;
const int READ_BUFFER_SIZE = 1024;
char readSerialBuffer[READ_BUFFER_SIZE];
int readSerialLength = 0;
int readSerialError = 0;
bool firstCharacter = false;

int ReadSerial(){
  while(1){
    int data = Serial1.read();
    if (data < 0){
      break;
    }
    
    if (!firstCharacter)
    {
      if (data == '{')
      {
        firstCharacter = true;
        readSerialBuffer[readSerialLength++] = char(data);
      }
    }

    else
    {
      if (data == '\n'){
        if(readSerialError == 1){
          readSerialError = 0;
          readSerialLength = 0;
          break;
        }
        readSerialBuffer[readSerialLength] = 0;
        readSerialData = String(readSerialBuffer);
        readSerialLength = 0;
        firstCharacter = false;
        return 1;
      } else {
        if(readSerialError == 0){
          readSerialBuffer[readSerialLength++] = char(data);
          if(readSerialLength >= READ_BUFFER_SIZE){
            readSerialError = 1;
          }
        }
      }
    }
  }
  return 0;
}

const int WRITE_BUFFER_SIZE = 1024*8;
const int SEND_BUFFER_SIZE = 32;
char serialWriteBuffer[WRITE_BUFFER_SIZE];
int serialWriteLength = 0;

int SerialWrite(String data){
  int n = data.length();
  if(serialWriteLength + n >= WRITE_BUFFER_SIZE){
    return -1; 
  }
  strcpy(&serialWriteBuffer[serialWriteLength], data.c_str());
  serialWriteLength += n;
  return 0;
}

int SerialWriteln(String data){
  int n = data.length();
  if(serialWriteLength + (n + 1) >= WRITE_BUFFER_SIZE){
    return -1; 
  }
  if(SerialWrite(data) < 0){
    return -1;
  }
  serialWriteBuffer[serialWriteLength++] = '\n';
  return 0;
}

int SerialSendBuffer(){
  while(1){
    if(serialWriteLength <= 0){
      return 0;
    }
    int n = serialWriteLength;
    if(n > SEND_BUFFER_SIZE){
      n = SEND_BUFFER_SIZE;
    }
    if(Serial1.availableForWrite() < n){
      return 0;
    }
    Serial1.write(serialWriteBuffer, n);
    serialWriteLength -= n;
    memcpy(serialWriteBuffer, &serialWriteBuffer[n], serialWriteLength);
  }
  return 0;
}

void OnStart()
{
  Serial.begin(9600);
  Serial1.begin(115200);
  //Serial.print("Serial1.availableForWrite(): ");
  //Serial.println(Serial1.availableForWrite());
  
  pinMode(builtinLedPin, OUTPUT);

  for (int i = 0; i < SENSOR_COUNT; i++)
  {
    pinMode(sensorPins[i], INPUT);
  }

  for (int m = 0; m < MOTOR_COUNT; m++)
  {
    for (int p = 0; p < 3; p++)
    {
      pinMode(motorPins[m][p], OUTPUT);
    }
  }

  digitalWrite(builtinLedPin, LOW);
}

void OnConnect(StaticJsonDocument<256> message)
{
  if(DEBUG_SERIAL_WRITE == 1){
    Serial.println("Init message received");
  }
  isConnected = true;

  if (message.containsKey("mc")){
    motorConf = message["mc"];
  } else {
    motorConf = 0;
  }

  builtinLedStatus = false;
  digitalWrite(builtinLedPin, builtinLedStatus);

  lastMessageTime = millis();
}

void OnUpdate()
{
  for (unsigned int i = 0; i < SENSOR_COUNT; i++)
  { 
    int sensorValue = analogRead(sensorPins[i]);
    SensorStatUpdate(i, sensorValue);
    if (sensorValue > colorSensorValues[i])
      colorSensorValues[i] = sensorValue;
  }

  unsigned long currentTime = millis();
  if (currentTime - lastTime >= 1000)
  {
    lastTime = currentTime;

    //Serial.println(motorMessageCount);
    //Serial.println(sensorMessageCount);

    motorMessageCount = 0;
    sensorMessageCount = 0;
  }

  if (currentTime - lastMessageTime >= connectionTimeout)
  {
    if(DEBUG_SERIAL_WRITE == 1){
      Serial.println("Connection timeout");
    }
    SerialWriteln(CreateErrorJson("Connection timeout"));

    OnDisconnect();
    isConnected = false;
  }


  if (currentTime - lastSensorsMessage >= sensorMessageInterval)
  {
    int n = serialWriteLength;

    lastSensorsMessage = currentTime;

    sensorMessageCount++;

    StaticJsonDocument<512> sensorValuesMessage;
    sensorValuesMessage["type"] = MessageType::SENSORS;

    JsonArray valuesArray = sensorValuesMessage.createNestedArray("v");

    for(unsigned int i = 0; i < SENSOR_COUNT; i++)
      valuesArray.add(colorSensorValues[i]);

    String outString = "";
    serializeJson(sensorValuesMessage, outString);

    //Serial1.println(outString);
    SerialWriteln(outString);
    
    for (unsigned int i = 0; i < SENSOR_COUNT; i++)
      colorSensorValues[i] = 0;
    
    if(n <= 0){ // assuming write buffer was empty 
      SensorsLogSend();
    }
  }
}

void OnMessage(MessageType messageType, StaticJsonDocument<256> message)
{
  switch (messageType)
  {
  case MessageType::INIT:
    break;

  case MessageType::DISCONNECT:
    OnDisconnect();
    isConnected = false;

    break;

  case MessageType::ERROR:
    break;

  case MessageType::MOTORS:
    {
      lastMessageTime = millis();

      motorMessageCount++;

      JsonArray motorValuesJson = message["v"].as<JsonArray>();

      int checksum = message["cs"];

      if (motorValuesJson[0].as<int>() + motorValuesJson[1].as<int>() + motorValuesJson[2].as<int>() + motorValuesJson[3].as<int>() != checksum)
      {
        SerialWriteln(CreateErrorJson("Checksum verification failed in motor packet"));
        return;
      }

      int mv1 = motorValuesJson[0];
      int mv2 = motorValuesJson[1];
      int mv3 = motorValuesJson[2];
      int mv4 = motorValuesJson[3];
      SetMotors(mv1, mv2, mv3, mv4);
    }

    break;

  case MessageType::SENSORS:
    break;

  case MessageType::SENSOR_STAT_RESET_RQ:
    SensorStatReset();
    break;
    
  case MessageType::SENSOR_STAT_READ_RQ:
    SensorStatGet();
    break;
  
  case MessageType::SENSOR_LOG_READ_RQ:
    SensorsLogGet(message);
    break;

  default:
    break;
  }
}

void OnDisconnect()
{
  if(DEBUG_SERIAL_WRITE == 1){
    Serial.println("Disconnected");
  }
  SetMotors(0, 0, 0, 0);
}
////////////////////////////////////////////////////////////
int sensorStatsMin[SENSOR_COUNT];
int sensorStatsMax[SENSOR_COUNT];
long sensorStatsSum[SENSOR_COUNT];
// histogram for each 1000/16 =cca64 values interval from ir sensors
const int HISTOGRAM_INTERVALS = 16; // 1000/64 = cca16
const int HISTOGRAM_INTERVALS_SHIFT = 6; // 2^6 = 64
const int HISTOGRAM_INTERVALS_MIN = 0;
const int HISTOGRAM_INTERVALS_MAX = 1023;

long sensorStatsHistogram[SENSOR_COUNT][HISTOGRAM_INTERVALS];
int sensorStatsUpdate = 0;

const int LOG_HISTORY = 6144;
const int LOG_SEND_MAX = 256;
const int SENSOR_LOG_ID_TIME = 90;
short sensorLog[SENSOR_COUNT][LOG_HISTORY];
int sensorLogPtrWrite = 0;
int sensorLogPtrRead = 0;
unsigned long sensorLogTimeStart = 0; 
int sensorLogTime[LOG_HISTORY];
int sensorLogReadDataId = -1;
int sensorLogReadDataFrom = 0;
int sensorLogReadDataCount = 0;
int sensorLogReadDataSent = 0;

void SensorStatUpdate(int sensorId, int sensorVal){
  if (!sensorStatsUpdate) return;
  
  if (sensorStatsMin[sensorId] > sensorVal){
    sensorStatsMin[sensorId] = sensorVal;
  }
  if (sensorStatsMax[sensorId] < sensorVal){
    sensorStatsMax[sensorId] = sensorVal;
  }

  sensorStatsSum[sensorId] += sensorVal;
  
  if(sensorVal < HISTOGRAM_INTERVALS_MIN){
    sensorStatsHistogram[sensorId][0]++;  
  }else
  if(sensorVal > HISTOGRAM_INTERVALS_MAX){
    sensorStatsHistogram[sensorId][HISTOGRAM_INTERVALS-1]++;
  } else {
    sensorStatsHistogram[sensorId][sensorVal>>HISTOGRAM_INTERVALS_SHIFT]++;
  }

  if (sensorId == 0) {
    if (LOG_COMM == 1)
    {
      communicationLogTime = micros() - communicationLogTimeStart;
      communicationLogTimeStart = micros();
      sensorLogTime[sensorLogPtrWrite] = communicationLogTime;
      communicationLogTime = -1;
    } else {
      sensorLogTime[sensorLogPtrWrite] = millis() - sensorLogTimeStart;
    } 
  }
  sensorLog[sensorId][sensorLogPtrWrite] = sensorVal;
   
  if (sensorId == SENSOR_COUNT-1)
  {
    if(sensorLogPtrWrite < LOG_HISTORY){
      sensorLogPtrWrite++; 
    } else {
      sensorLogPtrWrite = 0; 
    }

    if(sensorLogPtrWrite == sensorLogPtrRead){
      if(sensorLogPtrRead < LOG_HISTORY){
        sensorLogPtrRead++;
      } else {
        sensorLogPtrRead = 0; 
      }
    }
  }
}

void SensorStatReset(){
  sensorStatsUpdate = 1;
  
  for(int i = 0; i < SENSOR_COUNT; i++){
    sensorStatsMin[i] = 9999;
    sensorStatsMax[i] = -1;

    sensorStatsSum[i] = 0;
    
    for(int j = 0; j < HISTOGRAM_INTERVALS; j++){
      sensorStatsHistogram[i][j] = 0;
    }    
  }
  
  sensorLogPtrRead = 0;
  sensorLogPtrWrite = 0;
  sensorLogTimeStart = millis();

  sensorLogReadDataId = -1;
  sensorLogReadDataFrom = 0;
  sensorLogReadDataCount = 0;
  sensorLogReadDataSent = 0;

  communicationLogTimeStart = micros();

  StaticJsonDocument<128> sensorStatsResetMessage;

  sensorStatsResetMessage["type"] = MessageType::SENSOR_STAT_RESET_RS;
  sensorStatsResetMessage["result"] = "OK";

  String outString = "";
  serializeJson(sensorStatsResetMessage, outString);
  
  SerialWriteln(outString);
}

void SensorStatGet(){
  sensorStatsUpdate = 0;

  StaticJsonDocument<4096> sensorStatsValueMessage; 
  sensorStatsValueMessage["type"] = MessageType::SENSOR_STAT_READ_RS;
  sensorStatsValueMessage["result"] = "OK";

  JsonArray valuesMinArray = sensorStatsValueMessage.createNestedArray("v");
  JsonArray valuesMaxArray = sensorStatsValueMessage.createNestedArray("u");
  JsonArray valuesAvgArray = sensorStatsValueMessage.createNestedArray("w");


  for(unsigned int i = 0; i < SENSOR_COUNT; i++){
    valuesMinArray.add(sensorStatsMin[i]);
    valuesMaxArray.add(sensorStatsMax[i]);
  }
  
  JsonArray valuesArray = sensorStatsValueMessage.createNestedArray("h");
  for(unsigned int i = 0; i < SENSOR_COUNT; i++){
    long sum = 0;
    for (unsigned int j = 0; j < HISTOGRAM_INTERVALS; j++){
      sum += sensorStatsHistogram[i][j];
    }
    
    if (i == 0){
      sensorStatsValueMessage["count"] = sum;
    }
    if (sum > 0){  
      valuesAvgArray.add(int(sensorStatsSum[i]/sum));
      for (unsigned int j = 0; j < HISTOGRAM_INTERVALS/2; j++){
        // x is rounded up percentage of 2 Histogram values, so it would be easier to understand
        long y = sensorStatsHistogram[i][2*j] + sensorStatsHistogram[i][2*j+1];
        int x = double(y) / sum * 10000;
        x = (x + 5) / 10;
        if(x <= 0 && y > 0){
          x = 1;
        }
        valuesArray.add(x);  
      }
    } else {
      valuesAvgArray.add(-1);
    }
    
  }

  String outString = "";
  serializeJson(sensorStatsValueMessage, outString);
  
  SerialWriteln(outString);
}

void SensorsLogGet(StaticJsonDocument<256> message){
  sensorLogReadDataId = message["id"];
  sensorLogReadDataFrom = message["f"];
  sensorLogReadDataCount = message["c"];
  sensorLogReadDataSent = 0;

}

void SensorsLogSend(){
  if (sensorLogReadDataId < 0) return;

  StaticJsonDocument<6144> sensorsLogMessage; 
  sensorsLogMessage["type"] = MessageType::SENSOR_LOG_READ_RS;
  sensorsLogMessage["result"] = "OK";
  sensorsLogMessage["id"] = sensorLogReadDataId;
  sensorsLogMessage["f"] = sensorLogReadDataFrom + sensorLogReadDataSent;
  
  int x = sensorLogPtrWrite - sensorLogPtrRead;
  if (x < 0) x += LOG_HISTORY;
  sensorsLogMessage["s"] = x;

  int cnt = x - (sensorLogReadDataFrom + sensorLogReadDataSent);
  if(cnt < 0) cnt = 0;
  if(cnt > sensorLogReadDataCount - sensorLogReadDataSent) cnt = sensorLogReadDataCount - sensorLogReadDataSent;
  if(cnt > LOG_SEND_MAX) cnt = LOG_SEND_MAX;

  JsonArray valuesLogArray = sensorsLogMessage.createNestedArray("v");

  int ptr = sensorLogPtrRead + (sensorLogReadDataFrom + sensorLogReadDataSent);
  if (ptr > LOG_HISTORY) ptr -= LOG_HISTORY;  
  for(int i = 0; i < cnt; i++){
    if (sensorLogReadDataId == SENSOR_LOG_ID_TIME){
      valuesLogArray.add(sensorLogTime[ptr]);
    } else {
      valuesLogArray.add(sensorLog[sensorLogReadDataId][ptr]);
    }
    ptr++;
    if (ptr > LOG_HISTORY) ptr -= LOG_HISTORY;  
  }
  
  sensorLogReadDataSent += cnt;
  if(cnt == 0 || sensorLogReadDataSent >= sensorLogReadDataCount) sensorLogReadDataId = -1;

  String outString = "";
  serializeJson(sensorsLogMessage, outString);
  
  SerialWriteln(outString);
}


///////////////////////////////////////////////////////////



void setup()
{
  OnStart();
}

void loop()
{
  SerialSendBuffer();
  
  // If there is a new message available ...
  if (Serial1.available() > 0)
  {
    // Read input JSON
    //communicationLogTimeStart = micros();
    //String data = Serial1.readStringUntil('\n');
    int result = ReadSerial();
    //communicationLogTime = micros() - communicationLogTimeStart;
    if (result == 1){
      //communicationLogTimeStart = micros();
      StaticJsonDocument<256> message;
      DeserializationError err = deserializeJson(message, readSerialData);
      //communicationLogTime = micros() - communicationLogTimeStart;
  
      // Check for error in message deserialization
      if (err)
      {
        if(DEBUG_SERIAL_WRITE == 1){
          Serial.print(F("Deserialization failed: "));
          Serial.println(err.c_str());
        }
        message.clear();
  
        SerialWriteln(CreateErrorJson(err.c_str()));
      }
      else
      {
        int messageType = (message["type"] | -1);
  
        if (isConnected)
        {
          //communicationLogTimeStart = micros();
          OnMessage((MessageType)messageType, message);
          //communicationLogTime = micros() - communicationLogTimeStart;
        }
        else
        {
          if (messageType == MessageType::INIT)
          {
            OnConnect(message);
          }
        }
      } 
    }
  }

  if (isConnected)
  {
    OnUpdate();
  }
  else
  {
    // Blink builtin LED to indicate that there is no device connected
    unsigned long currentTime = millis();

    if (currentTime - lastTime >= 1000)
    {
      lastTime = currentTime;
      builtinLedStatus = !builtinLedStatus;
      digitalWrite(builtinLedPin, builtinLedStatus);
    }
  }
}

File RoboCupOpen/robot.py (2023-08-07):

from soccer_robot.soccer_robot import SoccerRobot

from soccer_robot.logger.logger_module import LoggerModule
from soccer_robot.interface.camera_module import CameraModule
from soccer_robot.interface.undercarriage_module import UndercarriageModule
from soccer_robot.interface.compass_module import CompassModule
from soccer_robot.interface.ui_module.ui_module import UIModule
from soccer_robot.interface.bluetooth_module import BluetoothModule

# TEMPORARY SOLUTION, should be handled by soccer_robot class in the future
from soccer_robot.visualization.visualizer_module import VisualizationModule

from soccer_robot.mathf import mathf
from soccer_robot.mathf.vector2 import Vector2
import soccer_robot.constants as con
from soccer_robot.utils.timer import Timer

import math
import os
import sys
import time

import RPi.GPIO as GPIO

KICKOFF_PUSH_TIME = 0

import RPi.GPIO as GPIO

class Robot(SoccerRobot):
    def on_start(self) -> None:

        GPIO.setup(16, GPIO.IN)

        LoggerModule.log_debug("Main Process pid: " + str(os.getpid()))

        self.motor_values = (0, 0, 0, 0)
        UndercarriageModule.set_motor_values(*self.motor_values)

        self.ball_position = [0, 0, 0, 0]
        self.goal_position = [0, 0, 0, 0]

        self.see_ball = False
        self.see_goal = False

        self.ball_angle = 0
        self.ball_dist = 0
        self.goal_center_angle = 0
        self.goal_dist = 0

        self.heading = 0

        self.active_i = []
        self.line = []

        self.lock_motors = True
        self.speed = 0
        self.shooting_speed = 0
        self.rotating_speed = 0

        self.backwards_speed = 0
        self.line_avoid_speed = 0

        self.seen_line = False
        self.anti_line_angle = 0
        self.line_timer = Timer()
        self.line_avoid_timer = con.LINE_AVOID_FAST

        self.last_ball_angle = 0
        self.looking_for_ball_phase = 0
        self.last_seen_ball_timer = Timer()

        self.goalie = False
        self.goalie_change_timer = Timer()

        self.should_defend = False
        self.defend_start_timer = Timer()

        self.start_button_timer = Timer()

        self.line_while_going_for_ball = 0

        self.rotating = False
        self.rotating_timer = Timer()

        self.goalie_status = 1

    def on_update(self) -> None:
        self.motor_values = (0, 0, 0, 0)

        # Set speeds from calibration
        self.speed = self.get_robot_speed()
        self.shooting_speed = self.get_robot_shooting_speed()
        self.rotating_speed = self.get_robot_rotating_speed()

        self.backwards_speed = self.speed
        self.line_avoid_speed = self.speed


        # Get data from other modules
        self.ball_position = CameraModule.get_ball_position()
        self.goal_position = CameraModule.get_goal_position()

        self.heading = CompassModule.get_heading()
        sensor_values = UndercarriageModule.get_color_sensor_values()
        self.lock_motors = UIModule.get_button_one_status()

        self.active_i = []
        for i, v in enumerate(sensor_values):
            if v > self.get_line_sensors_threshold():
                self.active_i.append(i)
        self.line = mathf.get_line_pos(self.active_i)

        self.see_ball = self.ball_position[2] > con.BALL_MIN_SIZE[0] and self.ball_position[3] > con.BALL_MIN_SIZE[1]
        self.see_goal = self.goal_position[2] > con.GOAL_MIN_SIZE[0] and self.goal_position[3] > con.GOAL_MIN_SIZE[1]

        self.ball_angle, self.ball_dist = mathf.img_coords_to_angle_dist(self.ball_position)

        goal_right_corner_angle = mathf.img_coords_to_angle_dist(
            [self.goal_position[0] + self.goal_position[2] / 2] + self.goal_position[1:],
            con.GOAL_REAL_SIZE, 1
        )[0]
        self.goal_center_angle, self.goal_dist = mathf.img_coords_to_angle_dist(self.goal_position, con.GOAL_REAL_SIZE, 1)
        goal_left_corner_angle = mathf.img_coords_to_angle_dist(
            [self.goal_position[0] - self.goal_position[2] / 2] + self.goal_position[1:],
            con.GOAL_REAL_SIZE, 1
        )[0]
        goal_width_angle = mathf.normalize_angle(goal_right_corner_angle - goal_left_corner_angle)

        if (self.see_ball):
            self.last_seen_ball_timer.reset()

        # Decide a goalie
        if BluetoothModule.is_connected() and not BluetoothModule.is_locked():
            if con.ROBOT_INDEX == con.GOALIE_MASTER_INDEX:
                is_time = self.goalie_change_timer.get() >= con.GOALIE_CHANGE_TIME
                if is_time:
                    self.goalie_change_timer.reset()
                    both_see = self.see_ball and BluetoothModule.see_ball()
                    other_is_near = both_see and BluetoothModule.get_ball_angle_dist()[1] <= self.ball_dist
                    self.goalie = BluetoothModule.see_ball() and (not self.see_ball or other_is_near)
            else:
                self.goalie = not BluetoothModule.is_goalie()
        else:
            self.goalie = False

        # PLAY ON GOAL
        # If the robot sees the ball and the goal, ...
        if (self.see_ball and self.see_goal):
            self.last_ball_angle = self.ball_angle

            # If ball angle is between goal corner angles = robot is in shooting position, ...
            if (mathf.is_angle_between(self.ball_angle, (goal_left_corner_angle) % 360, (goal_right_corner_angle) % 360)):
                self.set_status("goal shoot")
                self.goal_shoot()
            # Else robot needs to go to the suitable shooting position
            else:
                self.set_status("goal shooting pos")
                self.go_to_goal_shooting_pos()

        # PLAY ON NORTH
        elif (self.see_ball):
            self.last_ball_angle = self.ball_angle

            if (self.heading < 360 - con.GET_AROUND_ANGLE and self.heading > con.GET_AROUND_ANGLE) or (self.ball_angle < 360 - con.GET_AROUND_ANGLE and self.ball_angle > con.GET_AROUND_ANGLE):
                self.set_status("compass shooting pos")
                self.go_to_compass_shooting_pos()

            else:
                self.set_status("compass shoot")
                self.compass_shoot()

        # LOOK FOR BALL
        else:
            self.set_status("looking for ball")
            if self.goalie:
                self.back_off()
            else:
                self.look_for_ball()

        # If robot detects line for few times when he is trying to get to ball, do direct shot
        if (self.should_defend and con.ROBOT_DEFEND):
            if (not mathf.is_angle_between(self.heading, 120, 240)):
                self.defend()

        if (self.line_while_going_for_ball >= 3 and not self.should_defend):
            self.should_defend = True
            self.defend_start_timer.reset()

        if (self.should_defend):
            if (self.defend_start_timer.get() > 2000 or not self.see_ball):
                self.should_defend = False
                self.line_while_going_for_ball = 0
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

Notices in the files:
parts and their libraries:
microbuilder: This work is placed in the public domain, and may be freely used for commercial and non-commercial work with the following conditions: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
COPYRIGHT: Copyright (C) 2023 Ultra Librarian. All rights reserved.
